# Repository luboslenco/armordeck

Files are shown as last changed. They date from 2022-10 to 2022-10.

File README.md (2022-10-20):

# armordeck

ArmorDeck is a tiny game console powered by esp32 microcontroller which plays a DOOM port. It was built purely as a learning experiment.
It features 4MB RAM, 32MB flash, 128x128 oled screen with 65536 colors, 6 buttons and rechargeable battery. Bluetooth audio is doable but not yet implemented.

### Assembly

Parts used:
- 1x ESP32: [[1]](https://www.dfrobot.com/product-2195.html)
- 1x Display: [[1]](https://www.waveshare.com/1.5inch-rgb-oled-module.htm)
- 1x Battery: [[1]](https://rpishop.cz/li-pol/3450-li-pol-baterie-37v-2000mah.html), [[2]](https://www.aliexpress.com/item/33001806434.html)
- 1x Prototype PCB: [[1]](https://www.aliexpress.com/item/1005002835181164.html)
- 6x Microswitch: [[1]](https://www.aliexpress.com/item/1005004001434474.html)

3D printed parts:
- 1x [Case top](hw/top.stl)
- 1x [Case bottom](hw/bottom.stl)
- 6x [Button cap](hw/button.stl)

Step 1:
- Prepare all the parts. Begin with the case top.
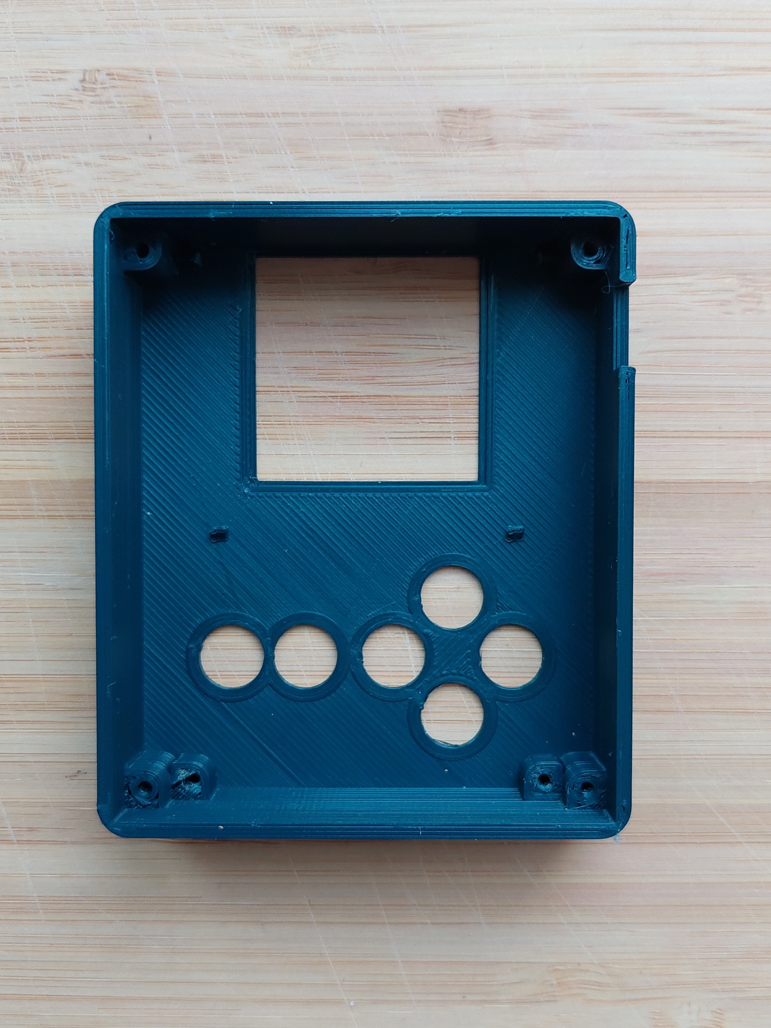
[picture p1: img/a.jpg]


Step 2:
- Insert microswitches into prototype PCB. Place button caps onto microswitches.
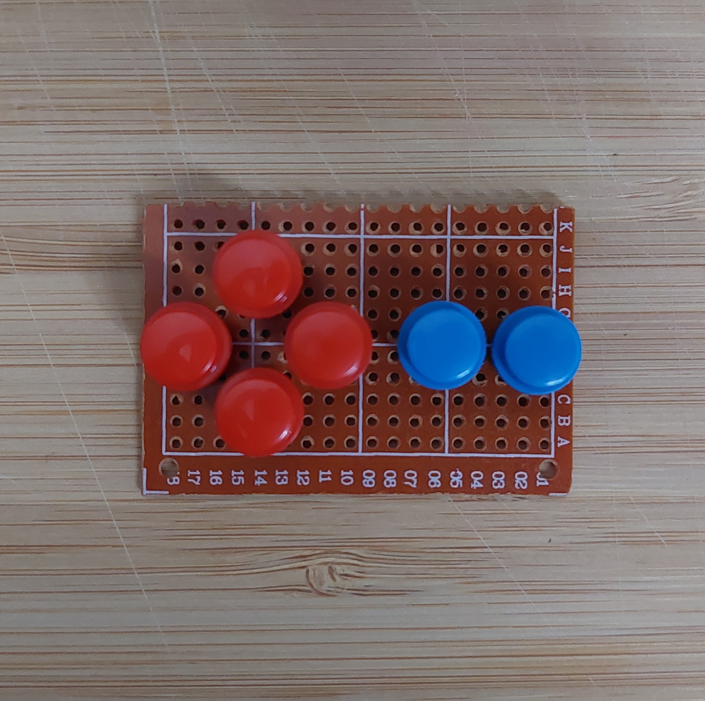
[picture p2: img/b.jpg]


Step 3:
- Insert display and buttons module into the case. Mount buttons module with 2xM2 screws.
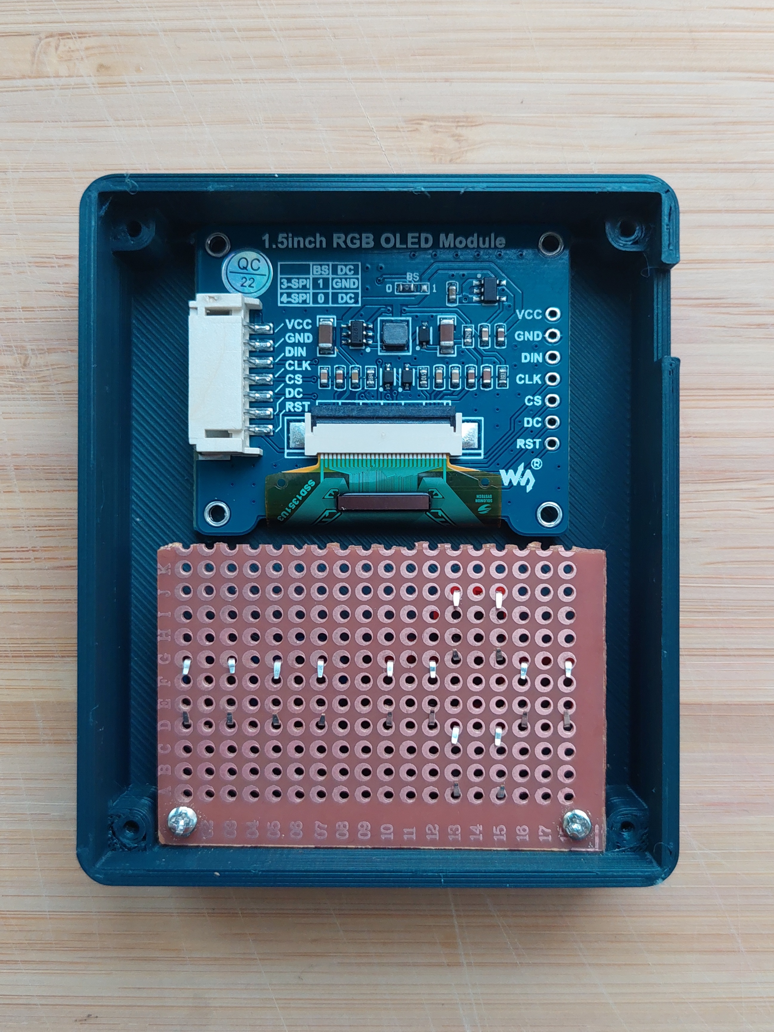
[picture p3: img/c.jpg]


Step 4:
- Insert esp32 microcontroller into the case.
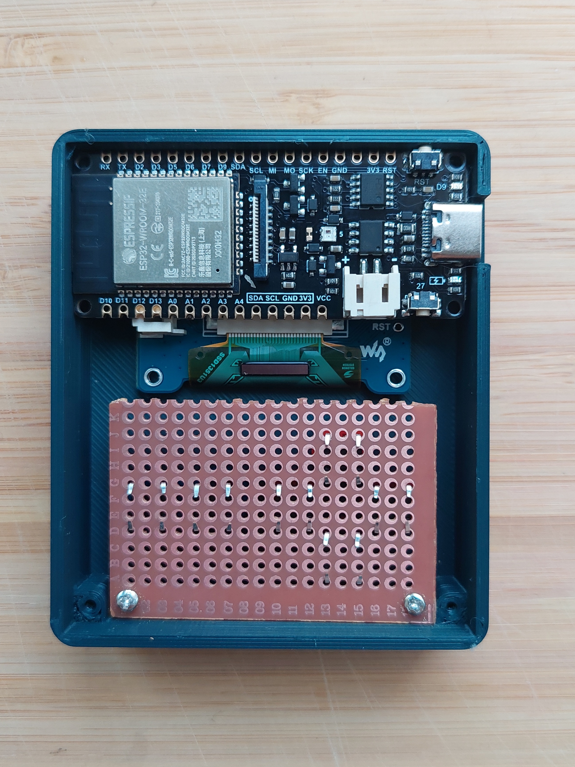
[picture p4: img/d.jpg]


Step 5:
- Solder display and button wires. Preferably with higher quality than pictured.
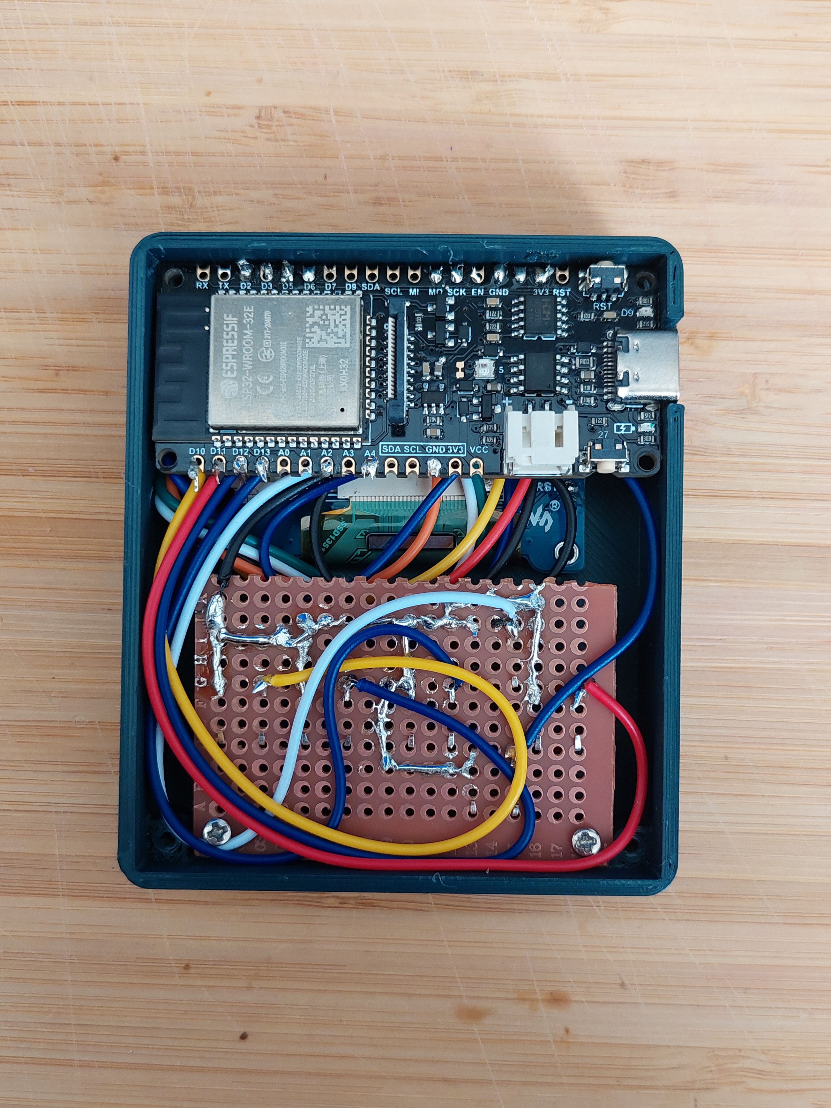
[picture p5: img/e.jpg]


```c
// Display pins
#define PIN_MOSE 23
#define PIN_CLK 18
#define PIN_DC 26
#define PIN_RST 25
#define PIN_CS 0
// Button pins
#define PIN_LEFT 16
#define PIN_UP 35
#define PIN_RIGHT 12
#define PIN_DOWN 15
#define PIN_A 4
#define PIN_B 17
```

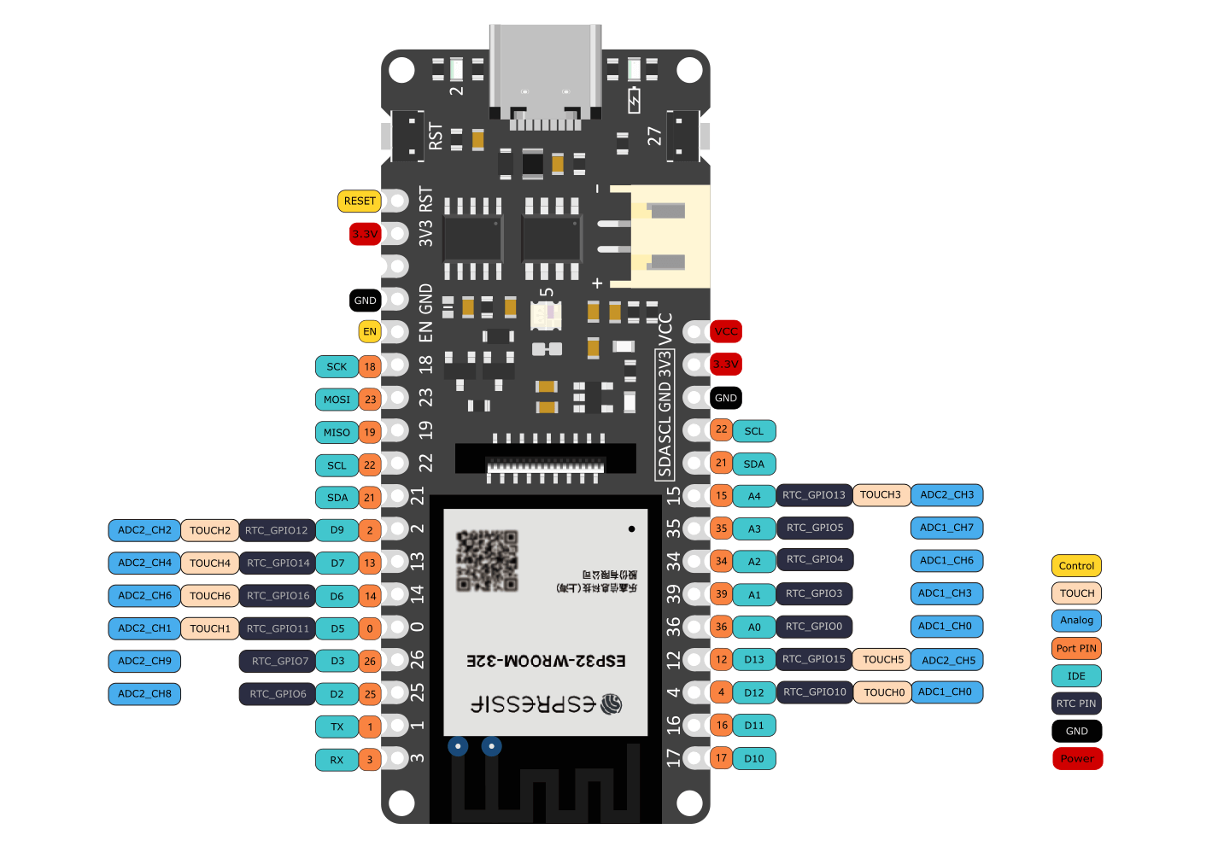
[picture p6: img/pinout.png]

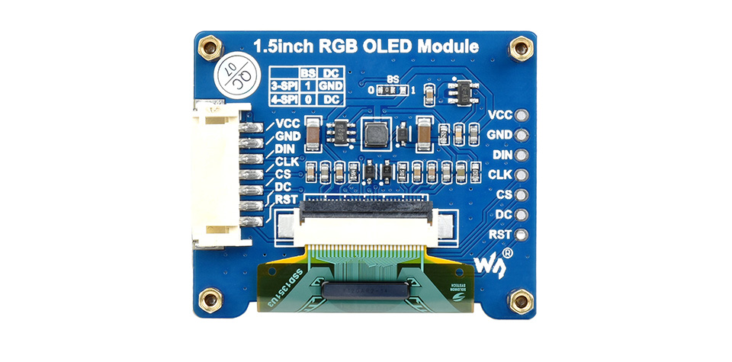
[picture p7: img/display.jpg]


Step 6:
- Insert battery and connect it to the esp32.
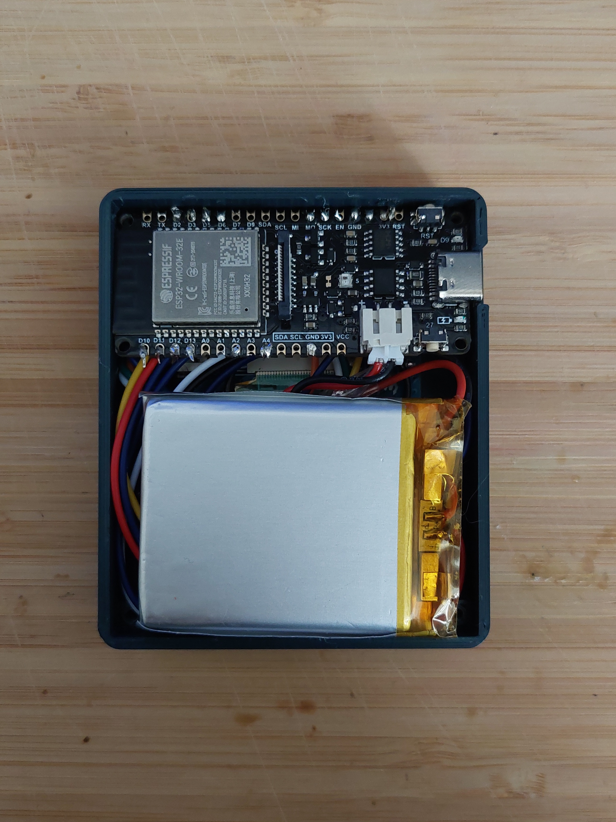
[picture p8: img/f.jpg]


Step 7:
- Place the case bottom and mount it with 4xM2 screws. Done!
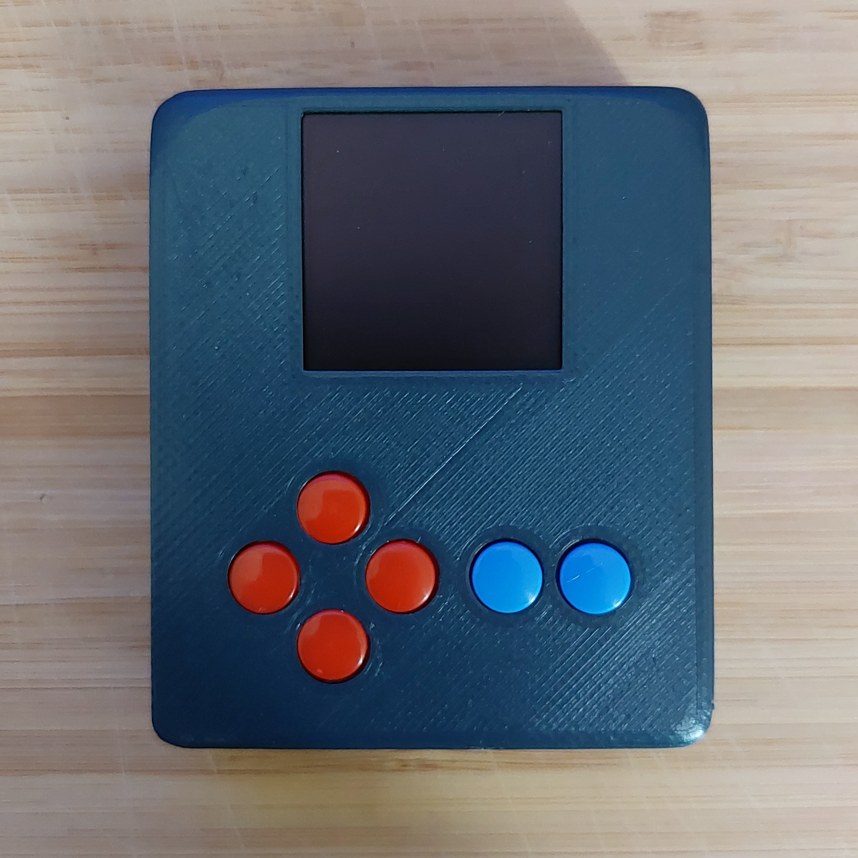
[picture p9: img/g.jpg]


### Compile

- Connect armordeck to a computer via a usb-c cable.
- Build and flash a project located at `armordeck/esp32` via [esp-idf](https://docs.espressif.com/projects/esp-idf/en/stable/esp32/get-started/vscode-setup.html).
- *or*
- Flash `armordeck/esp32/bin/armordeck.bin` file directly via [flash download tools](https://www.espressif.com/en/support/download/other-tools).

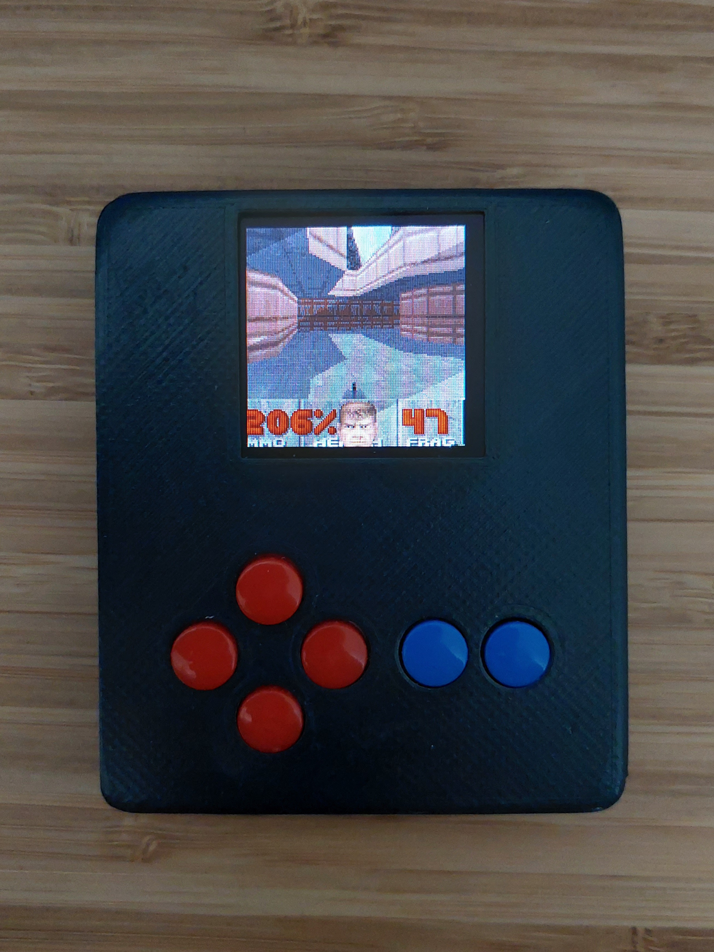
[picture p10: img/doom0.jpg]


System controls:
- Press `button a` + `button b` to enter deep sleep.
- Press `button up` + `button down` + `button left` + `button right` to reboot.

Simulator:
- Run `Kinc/make` at `armordeck/simulator`.
- Build and run generated project at `armordeck/simulator/build/`.

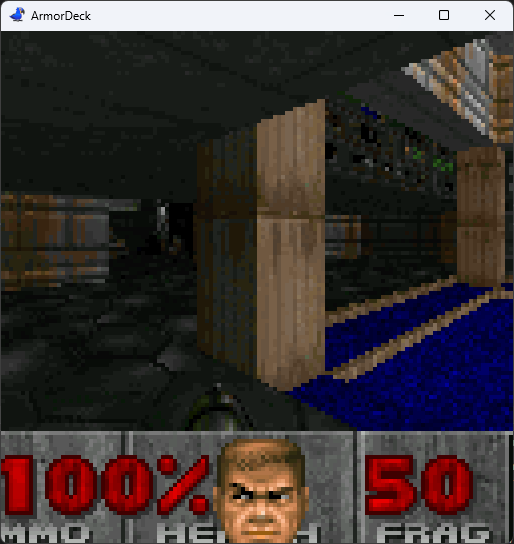
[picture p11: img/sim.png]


Doom port is based on:
- https://github.com/NordicPlayground/nrf-doom
- https://github.com/kilograham/rp2040-doom
- https://github.com/fabiangreffrath/crispy-doom
- https://github.com/chocolate-doom/chocolate-doom
- https://github.com/ozkl/doomgeneric
- https://github.com/floooh/doom-sokol
- https://github.com/Kinc-Samples/Doom-Kinc

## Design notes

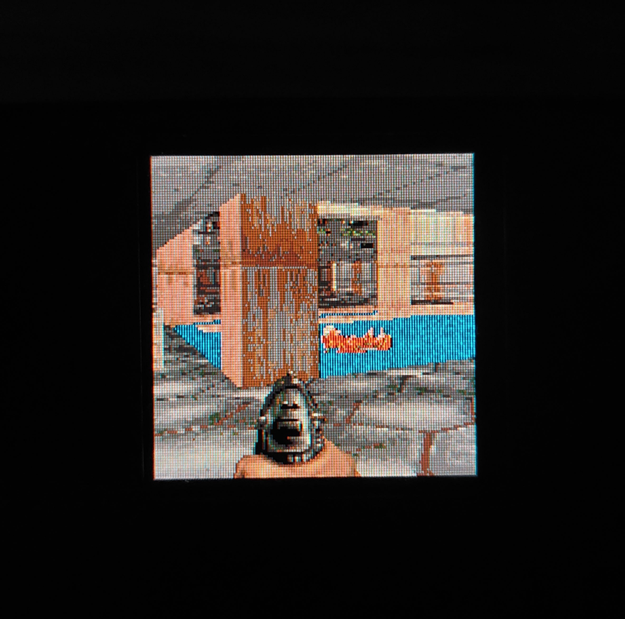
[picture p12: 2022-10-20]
img/doom2.jpg

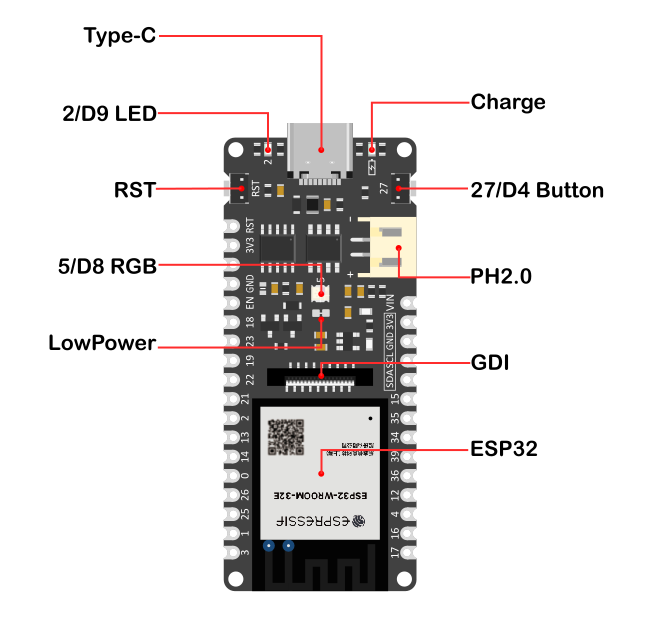
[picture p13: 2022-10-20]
img/board.png

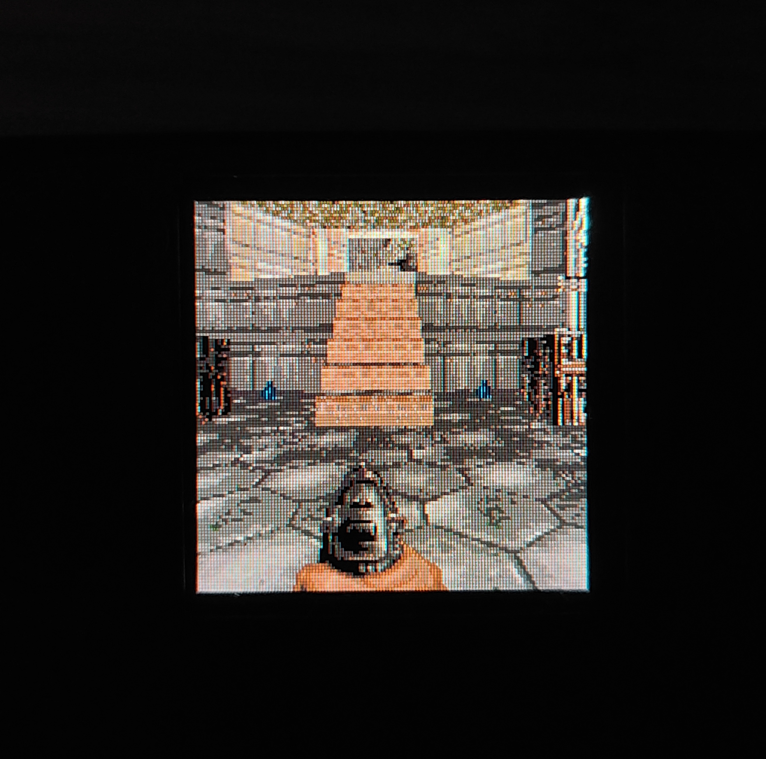
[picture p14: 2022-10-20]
img/doom3.jpg

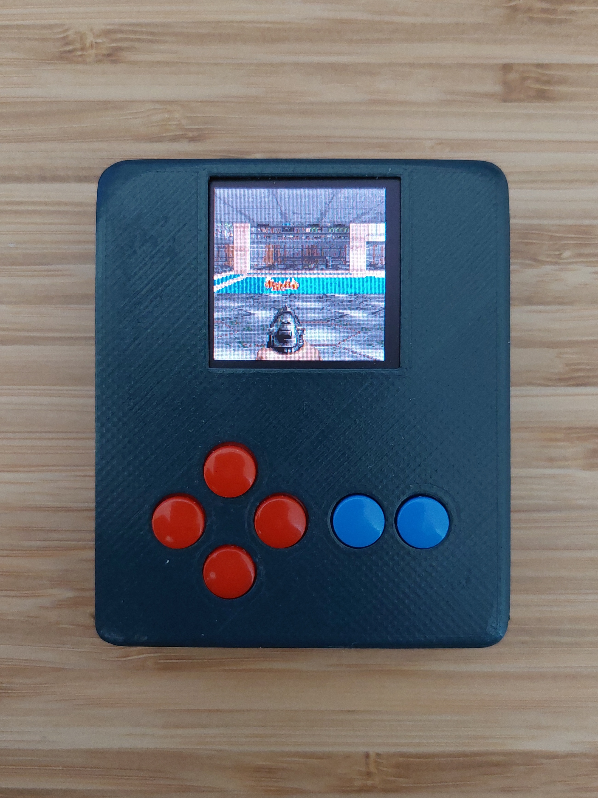
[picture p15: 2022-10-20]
img/h.jpg

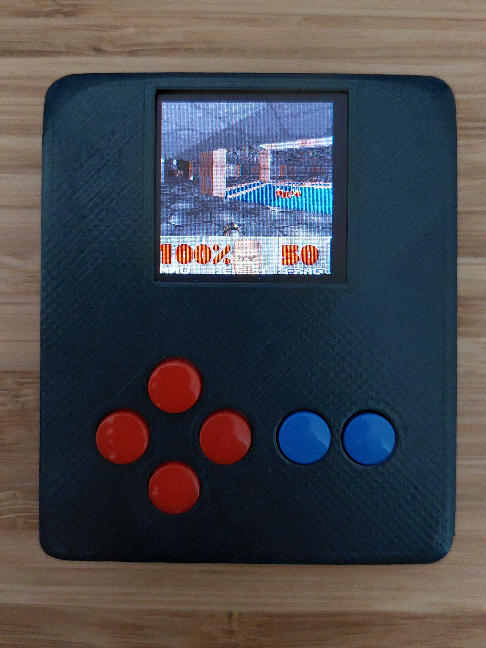
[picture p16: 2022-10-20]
img/doom1.jpg

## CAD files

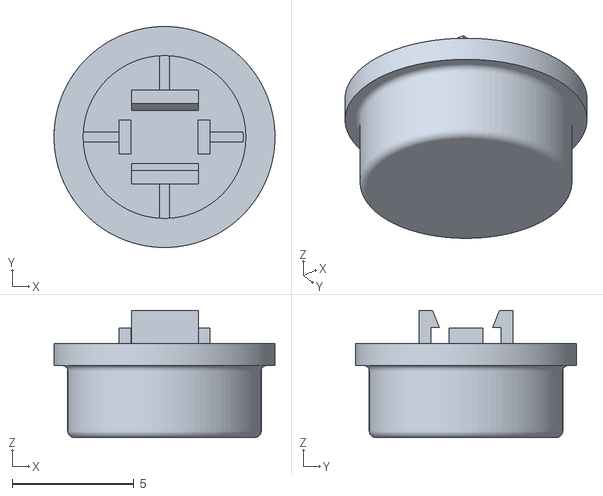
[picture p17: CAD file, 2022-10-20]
hw/button.stl
9.08 x 9.08 x 5.23

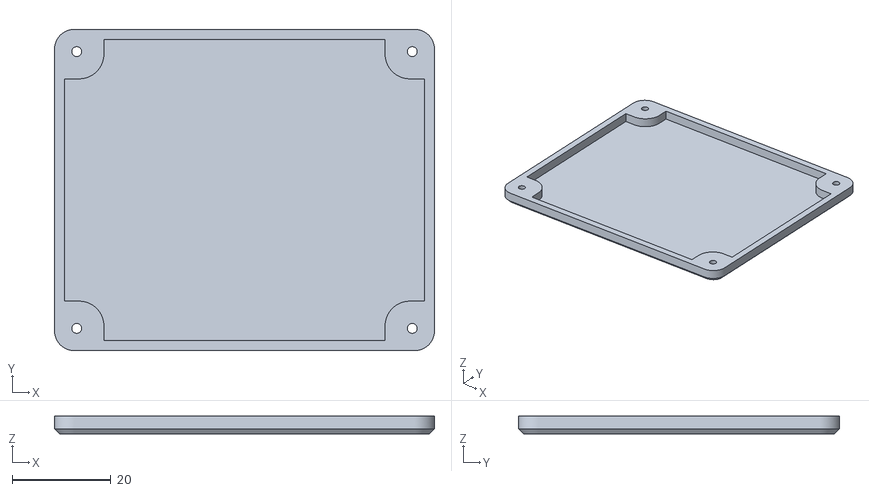
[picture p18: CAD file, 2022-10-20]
hw/bottom.stl
76.9 x 65.0 x 3.55

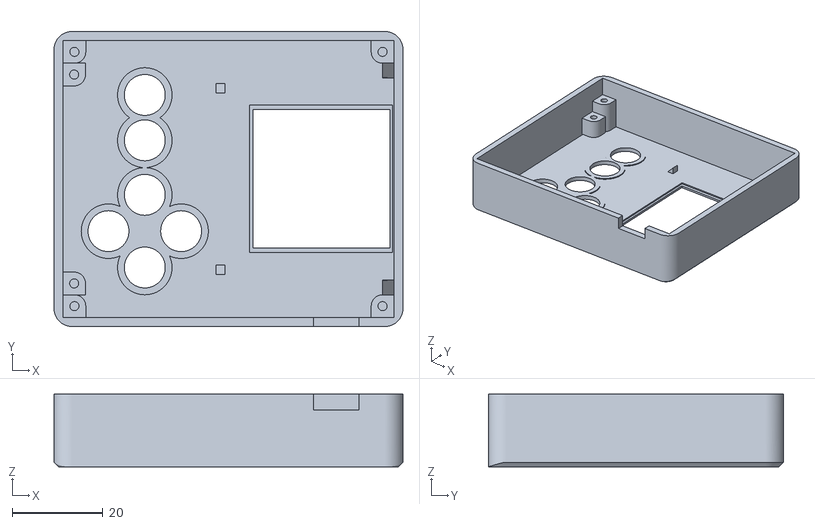
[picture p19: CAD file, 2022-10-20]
hw/top.stl
76.9 x 65.0 x 16.0

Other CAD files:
hw/case.blend

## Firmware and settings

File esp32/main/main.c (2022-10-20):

#include <string.h>
#include <stdio.h>
#include <freertos/FreeRTOS.h>
#include <freertos/task.h>
#include <driver/gpio.h>
#include <esp_sleep.h>
#include <sdkconfig.h>
#include <driver/rtc_io.h>
#include "display.h"
#include "doom.h"

#define PIN_MOSE 23
#define PIN_CLK 18
#define PIN_DC 26
#define PIN_RST 25
#define PIN_CS 0
#define PIN_LEFT 16
#define PIN_UP 35
#define PIN_RIGHT 12
#define PIN_DOWN 15
#define PIN_A 4
#define PIN_B 17

void app_main(void) {
	display_init(PIN_DC, PIN_CS);

	gpio_set_pull_mode(PIN_UP, GPIO_PULLUP_ONLY);
	gpio_set_pull_mode(PIN_DOWN, GPIO_PULLUP_ONLY);
	gpio_set_pull_mode(PIN_LEFT, GPIO_PULLUP_ONLY);
	gpio_set_pull_mode(PIN_RIGHT, GPIO_PULLUP_ONLY);
	gpio_set_pull_mode(PIN_A, GPIO_PULLUP_ONLY);
	gpio_set_pull_mode(PIN_B, GPIO_PULLUP_ONLY);

	while (1) {
		doom_run();

		// Enter sleep, PIN_DOWN to wake up
		if (gpio_get_level(PIN_B) == 0 && gpio_get_level(PIN_A) == 0) {
			display_shutdown();
			rtc_gpio_pullup_en(GPIO_NUM_15);
			rtc_gpio_pulldown_dis(GPIO_NUM_15);
			rtc_gpio_hold_en(GPIO_NUM_15);
			esp_sleep_enable_ext0_wakeup(GPIO_NUM_15, 0);
			esp_deep_sleep_start();
		}

		// Reset
		if (gpio_get_level(PIN_UP) == 0 && gpio_get_level(PIN_DOWN) == 0 && gpio_get_level(PIN_LEFT) == 0 && gpio_get_level(PIN_RIGHT) == 0) {
			esp_restart();
		}

		display_show();
	}
}

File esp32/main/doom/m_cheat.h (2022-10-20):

//
// Copyright(C) 1993-1996 Id Software, Inc.
// Copyright(C) 2005-2014 Simon Howard
//
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
// DESCRIPTION:
//	Cheat code checking.
//


#ifndef __M_CHEAT__
#define __M_CHEAT__

//
// CHEAT SEQUENCE PACKAGE
//

// declaring a cheat

#define CHEAT(value, parameters) \
    { value, sizeof(value) - 1, parameters, 0, 0, "" }

#ifndef DOOM_TINY
#define MAX_CHEAT_LEN 25
#define MAX_CHEAT_PARAMS 5
#else
#define MAX_CHEAT_LEN 1
#define MAX_CHEAT_PARAMS 1
#endif

typedef struct PACKEDATTR
{
    // settings for this cheat

    char sequence[MAX_CHEAT_LEN];
    size_t sequence_len;
    int parameter_chars;

    // state used during the game

    size_t chars_read;
    int param_chars_read;
    char parameter_buf[MAX_CHEAT_PARAMS];
} cheatseq_t;

int
cht_CheckCheat
( cheatseq_t*		cht,
  char			key );


void
cht_GetParam
( cheatseq_t*		cht,
  char*			buffer );


#endif

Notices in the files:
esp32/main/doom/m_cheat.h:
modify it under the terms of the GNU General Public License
